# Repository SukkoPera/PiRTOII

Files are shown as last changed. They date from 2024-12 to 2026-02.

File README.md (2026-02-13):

# PiRTO II





PiRTO II if a flash multicart for the Mattel Intellivision based on the Raspberry Pico.

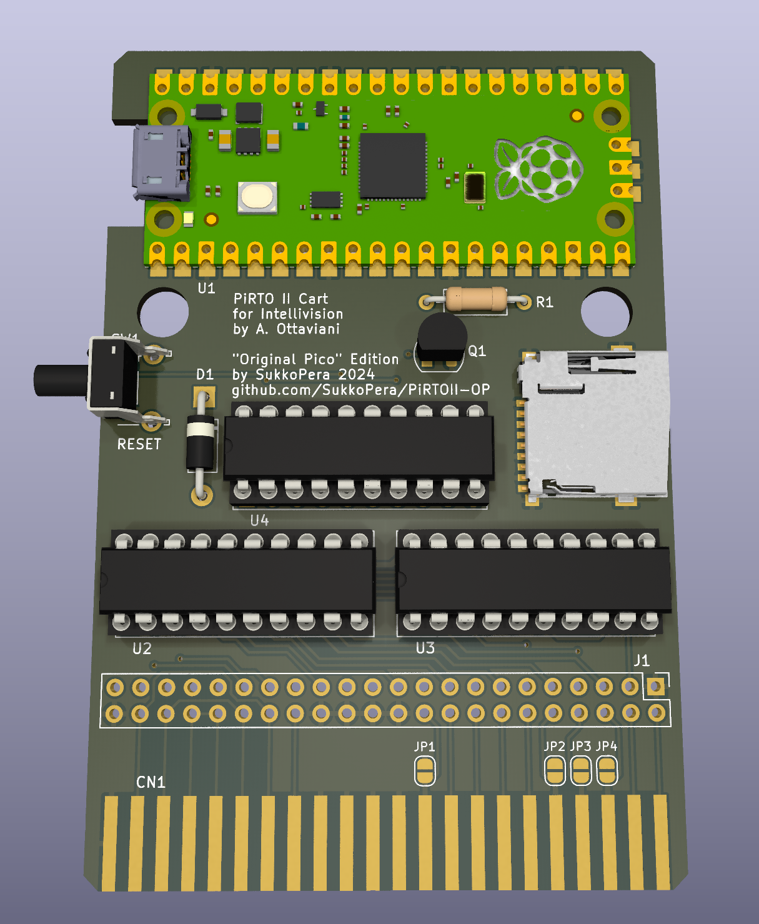
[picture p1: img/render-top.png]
Board


## Summary
This is my variation on [Andrea Ottaviani's PiRTO II](https://github.com/aotta/PiRTOII) flash multicart for the Mattel Intellivision.

My original goal was to adapt it in order to use original Pico boards, of which I had plenty. While studying the project I decided to introduce proper level shifting and a MicroSD card slot (since the original Pico has less flash space than the purple clones used in the original project). All of this eventually made the project very similar to Andrea's [first version of the cart](https://github.com/aotta/PiRTO), of which I was unaware of the time, but it uses through-hole components and one less chip.

## Usage
The Pico must be flashed with some firmware. You have a couple of choices:
- If you want to use Andrea's original firmware, you have to use the version from this page, which was changed to reflect the different pin mapping. Do **NOT** use the firmware from the original project, I will try to incorporate any upstream changes. This firmware has **NO SUPPORT** for the SD card slot.
- storm_walker has updated Andrea's firmware to support the SD card slot. You can get his version from [the sd_support branch](https://github.com/SukkoPera/PiRTOII/tree/sd_support). As far as I'm aware, this version **ONLY** supports the SD card slot. Any ROMs stored in the Pico's flash memory will not be usable.
- Alternatively, you can use [the Minty firmware from Gennaro Tortone](https://github.com/gtortone/Minty), which supports this variant starting from version 1.2. This should support both ROMs from the Pico's flash memory and from the SD card.

For any other needs, please refer to [the original project](https://github.com/aotta/PiRTOII) or to the [AtariAge forum](https://forums.atariage.com/forum/125-intellivision-aquarius/).

## Assembly
This board was designed **for the original Raspberry Pico board**, so either use that or a clone that has the same pinout. It's your responsibility to ascertain that.

U2/3/4 **MUST** be 74LVC245. Do **NOT** get these from China, as they will likely be HC chips with just different (incorrect) markings. Rather get them from Mouser, Digikey, RS, etc.

Other BJTs will probably work for Q1, just make sure they have the same pinout.

JP1/2/3/4 are experimental jumpers and all of them **except** JP4 **MUST** be closed for the moment.

## Releases
If you want to get this board produced, you are recommended to get [the latest release](https://github.com/SukkoPera/PiRTOII/releases) rather than the current git version, as the latter might be under development and is not guaranteed to be working.

Every release is accompanied by its Bill Of Materials (BOM) file and any relevant notes about it, which you are recommended to read carefully.

## License
Despite [an effort to clear things up](https://github.com/aotta/PiRTOII/issues/2), the license status of Andrea's original board is unclear, so I don't really know what to do. I don't want to add or remove any limitations compared to the original project, so please get in touch with him before you use this project in any way.

Still, let me point out that this PiRTOII variation is provided to you ‘as is’ and without any express or implied warranties whatsoever with respect to its functionality, operability or use, including, without limitation, any implied warranties of merchantability, fitness for a particular purpose or infringement. We expressly disclaim any liability whatsoever for any direct, indirect, consequential, incidental or special damages, including, without limitation, lost revenues, lost profits, losses resulting from business interruption or loss of data, regardless of the form of action or legal theory under which the liability may be asserted, even if advised of the possibility or likelihood of such damages.

## Support the Project
If you want to get some boards manufactured, you can get them from PCBWay through this link:

PCB from PCBWay (https://www.pcbway.com/project/shareproject/PiRTOII_Flash_multicart_for_the_Mattel_Intellivision_Original_Pico_Version_95662f2b.html)

You get my gratitude and cheap, professionally-made and good quality PCBs, I get some credit that will help with this and [other projects](https://www.pcbway.com/project/member/?bmbno=72D33927-5EF6-42). You won't even have to worry about the various PCB options, it's all pre-configured for you!

Also, if you still have to register, [you can use this link](https://pcbway.com/g/Nz7XZs) to get some bonus initial credit (and yield me some more).

You can also buy me a coffee if you want, all the money collected this way will actually go to charity:



## Thanks
Of course, I would like to thank Andrea for his original project.

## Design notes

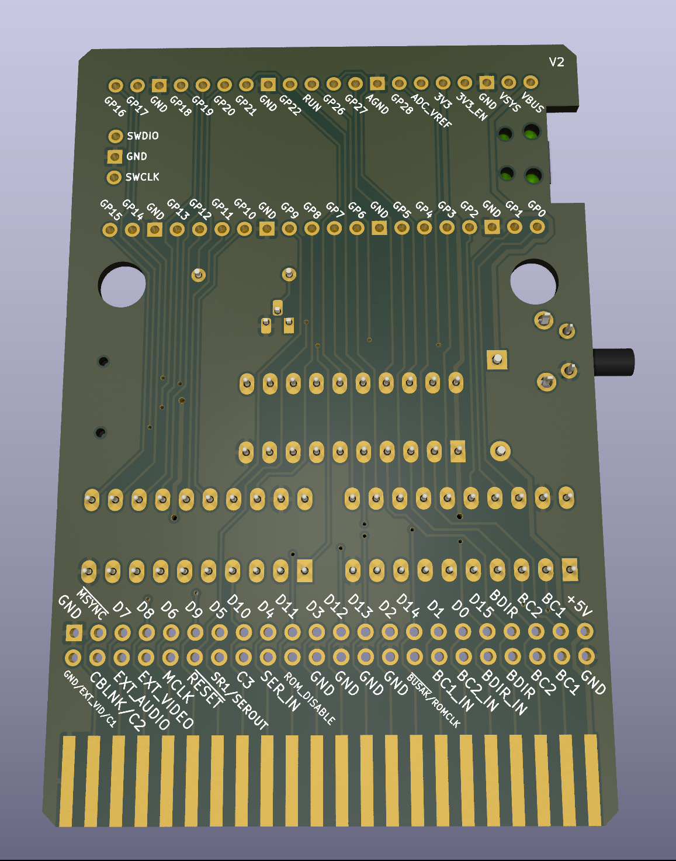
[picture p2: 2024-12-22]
img/render-bottom.png

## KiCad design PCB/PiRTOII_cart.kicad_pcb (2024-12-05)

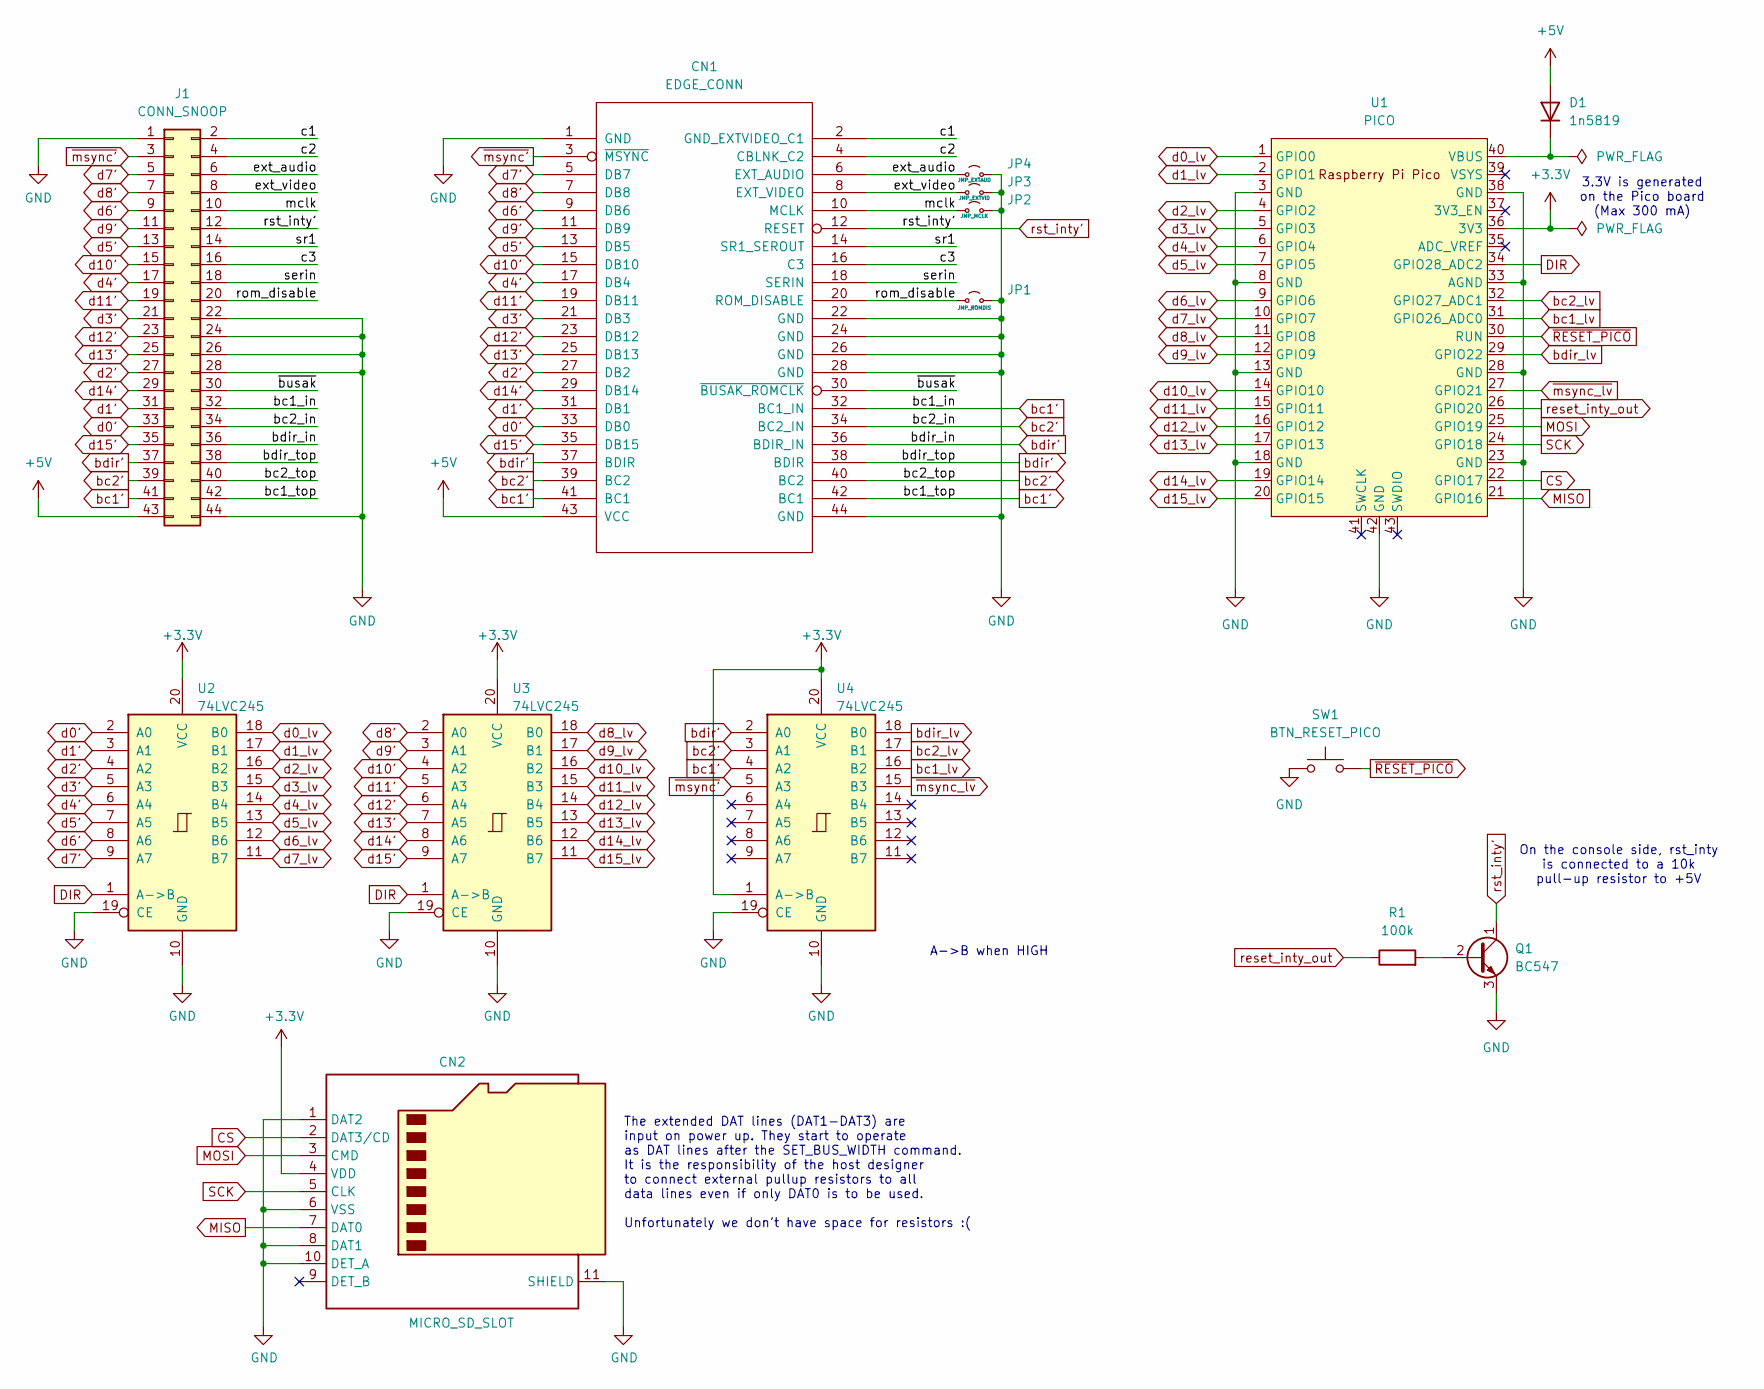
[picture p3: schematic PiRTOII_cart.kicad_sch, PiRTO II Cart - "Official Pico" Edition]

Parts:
CN1: EDGE_CONN; Intellivision_Edge_Connector
CN2: MICRO_SD_SLOT; GCT-MEM2055-00-190-01-A
D1: 1n5819; D_DO-41_SOD81_P10.16mm_Horizontal
J1: CONN_SNOOP; PinHeader_2x22_P2.54mm_Vertical
JP1: JMP_ROMDIS; SolderJumper-2_P1.3mm_Open_RoundedPad1.0x1.5mm
JP2: JMP_MCLK; SolderJumper-2_P1.3mm_Open_RoundedPad1.0x1.5mm
JP3: JMP_EXTVID; SolderJumper-2_P1.3mm_Open_RoundedPad1.0x1.5mm
JP4: JMP_EXTAUD; SolderJumper-2_P1.3mm_Open_RoundedPad1.0x1.5mm
Q1: BC547; TO-92_HandSolder
R1: 100k; R_Axial_DIN0207_L6.3mm_D2.5mm_P10.16mm_Horizontal
SW1: BTN_RESET_PICO; SW_Tactile_SPST_Angled_PTS645Vx83-2LFS
U1: PICO; RPi_Pico_SMD_TH
U2, U3, U4: 74LVC245; DIP-20_W7.62mm_Socket_LongPads

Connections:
+3.3V: CN2.4 (VDD), U1.36 (3V3), U2.20 (VCC), U3.20 (VCC), U4.1 (A->B), U4.20 (VCC)
+5V: CN1.43 (VCC), D1.2 (A), J1.43
/c1: CN1.2 (GND_EXTVIDEO_C1), J1.2
/c2: CN1.4 (CBLNK_C2), J1.4
/c3: CN1.16 (C3), J1.16
/ext_audio: CN1.6 (EXT_AUDIO), J1.6, JP4.1 (A)
/ext_video: CN1.8 (EXT_VIDEO), J1.8, JP3.1 (A)
/mclk: CN1.10 (MCLK), J1.10, JP2.1 (A)
/rom_disable: CN1.20 (ROM_DISABLE), J1.20, JP1.1 (A)
/serin: CN1.18 (SERIN), J1.18
/sr1: CN1.14 (SR1_SEROUT), J1.14
/~busak: CN1.30 (~BUSAK_ROMCLK), J1.30
CS: CN2.2 (DAT3/CD), U1.22 (GPIO17)
DIR: U1.34 (GPIO28_ADC2), U2.1 (A->B), U3.1 (A->B)
GND: CN1.1 (GND), CN1.22 (GND), CN1.24 (GND), CN1.26 (GND), CN1.28 (GND), CN1.44 (GND), CN2.1 (DAT2), CN2.6 (VSS), CN2.8 (DAT1), CN2.10 (DET_A), CN2.11 (SHIELD), J1.1, J1.22, J1.24, J1.26, J1.28, J1.44, JP1.2 (B), JP2.2 (B), JP3.2 (B), JP4.2 (B), Q1.3 (E), SW1.1, U1.3 (GND), U1.8 (GND), U1.13 (GND), U1.18 (GND), U1.23 (GND), U1.28 (GND), U1.33 (AGND), U1.38 (GND), U1.42 (GND), U2.10 (GND), U2.19 (CE), U3.10 (GND), U3.19 (CE), U4.10 (GND), U4.19 (CE)
MISO: CN2.7 (DAT0), U1.21 (GPIO16)
MOSI: CN2.3 (CMD), U1.25 (GPIO19)
unnamed: D1.1 (K), U1.40 (VBUS)
unnamed: Q1.2 (B), R1.2
SCK: CN2.5 (CLK), U1.24 (GPIO18)
bc1': CN1.32 (BC1_IN), CN1.41 (BC1), CN1.42 (BC1), J1.32, J1.41, J1.42, U4.4 (A2)
bc1_lv: U1.31 (GPIO26_ADC0), U4.16 (B2)
bc2': CN1.34 (BC2_IN), CN1.39 (BC2), CN1.40 (BC2), J1.34, J1.39, J1.40, U4.3 (A1)
bc2_lv: U1.32 (GPIO27_ADC1), U4.17 (B1)
bdir': CN1.36 (BDIR_IN), CN1.37 (BDIR), CN1.38 (BDIR), J1.36, J1.37, J1.38, U4.2 (A0)
bdir_lv: U1.29 (GPIO22), U4.18 (B0)
d0': CN1.33 (DB0), J1.33, U2.2 (A0)
d0_lv: U1.1 (GPIO0), U2.18 (B0)
d1': CN1.31 (DB1), J1.31, U2.3 (A1)
d1_lv: U1.2 (GPIO1), U2.17 (B1)
d2': CN1.27 (DB2), J1.27, U2.4 (A2)
d2_lv: U1.4 (GPIO2), U2.16 (B2)
d3': CN1.21 (DB3), J1.21, U2.5 (A3)
d3_lv: U1.5 (GPIO3), U2.15 (B3)
d4': CN1.17 (DB4), J1.17, U2.6 (A4)
d4_lv: U1.6 (GPIO4), U2.14 (B4)
d5': CN1.13 (DB5), J1.13, U2.7 (A5)
d5_lv: U1.7 (GPIO5), U2.13 (B5)
d6': CN1.9 (DB6), J1.9, U2.8 (A6)
d6_lv: U1.9 (GPIO6), U2.12 (B6)
d7': CN1.5 (DB7), J1.5, U2.9 (A7)
d7_lv: U1.10 (GPIO7), U2.11 (B7)
d8': CN1.7 (DB8), J1.7, U3.2 (A0)
d8_lv: U1.11 (GPIO8), U3.18 (B0)
d9': CN1.11 (DB9), J1.11, U3.3 (A1)
d9_lv: U1.12 (GPIO9), U3.17 (B1)
d10': CN1.15 (DB10), J1.15, U3.4 (A2)
d10_lv: U1.14 (GPIO10), U3.16 (B2)
d11': CN1.19 (DB11), J1.19, U3.5 (A3)
d11_lv: U1.15 (GPIO11), U3.15 (B3)
d12': CN1.23 (DB12), J1.23, U3.6 (A4)
d12_lv: U1.16 (GPIO12), U3.14 (B4)
d13': CN1.25 (DB13), J1.25, U3.7 (A5)
d13_lv: U1.17 (GPIO13), U3.13 (B5)
d14': CN1.29 (DB14), J1.29, U3.8 (A6)
d14_lv: U1.19 (GPIO14), U3.12 (B6)
d15': CN1.35 (DB15), J1.35, U3.9 (A7)
d15_lv: U1.20 (GPIO15), U3.11 (B7)
reset_inty_out: R1.1, U1.26 (GPIO20)
rst_inty': CN1.12 (RESET), J1.12, Q1.1 (C)
~RESET_PICO: SW1.2, U1.30 (RUN)
~msync': CN1.3 (~MSYNC), J1.3, U4.5 (A3)
~msync_lv: U1.27 (GPIO21), U4.15 (B3)

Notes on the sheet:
A->B when HIGH
3.3V is generated on the Pico board (Max 300 mA)
On the console side, rst_inty is connected to a 10k pull-up resistor to +5V
The extended DAT lines (DAT1-DAT3) are input on power up. They start to operate as DAT lines after the SET_BUS_WIDTH command. It is the responsibility of the host designer to connect external pullup resistors to all data lines even if only DAT0 is to be used. Unfortunately we don't have space for r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

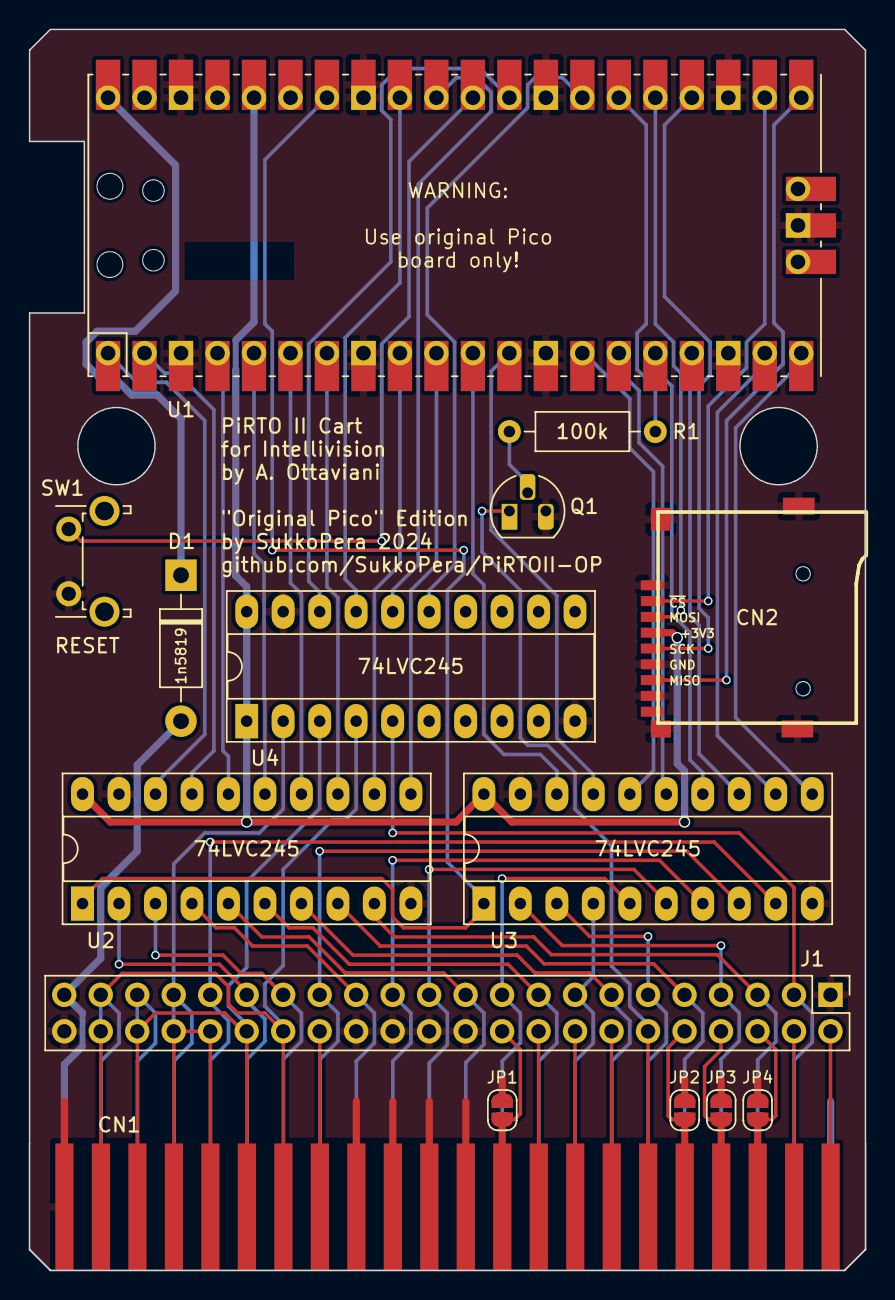
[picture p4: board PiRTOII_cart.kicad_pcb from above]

Board: 2 copper layers, 58.2 x 86.4 mm, 15 parts (0 on the bottom side), 63 nets.

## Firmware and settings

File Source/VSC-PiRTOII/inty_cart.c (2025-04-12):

/*
//                       PiRTO II Flash MultiCART by Andrea Ottaviani 2024
//
//  Intellivision flash multicart based on Raspberry Pico board -
//
//  More info on https://github.com/aotta/ 
//
//   parts of code are directly from the A8PicoCart project by Robin Edwards 2023
//  
//   Needs to be a release NOT debug build for the cartridge emulation to work
// 
//   Edit myboard.h depending on the type of flash memory on the pico clone//
//
//   v. 1.0 2024-05-04 : Initial version for Pi Pico 
//
*/

//#define intydebug // for debug print on intyscreen

#include <stdio.h>
#include <stdlib.h>
#include <string.h>
#include "pico/multicore.h"
#include "hardware/gpio.h"
#include "pico/platform.h"
#include "pico/stdlib.h"
#include "hardware/vreg.h"
#include "pico/divider.h"
#include "hardware/flash.h"
#include "hardware/sync.h"
#include "hardware/clocks.h"

#include "rom.h"

#include "tusb.h"
#include "ff.h"
#include "fatfs_disk.h"

#include "inty_cart.h"


// Pico pin usage definitions

#define B0_PIN    0
#define B1_PIN    1
#define B2_PIN    2
#define B3_PIN    3
#define B4_PIN    4
#define B5_PIN    5
#define B6_PIN    6
#define B7_PIN    7
#define F0_PIN    8
#define F1_PIN    9
#define F2_PIN    10
#define F3_PIN    11
#define F4_PIN    12
#define F5_PIN    13
#define F6_PIN    14
#define F7_PIN    15
#define BDIR_PIN  22
#define BC2_PIN   27
#define BC1_PIN   26
#define MSYNC_PIN 21
#define RST_PIN   20
#define LED_PIN   25
#define DIR_PIN   28	//  TO PIN 1 LVC245, HIGH= A->B (INPUT 5V TO 3.3V, inty -> pico) LOW= B->A (OUTPUT 3.3V TO 5V, pico -> inty)

// Pico pin usage masks
#define B0_PIN_MASK     0x00000001L // gpio 0
#define B1_PIN_MASK     0x00000002L
#define B2_PIN_MASK     0x00000004L
#define B3_PIN_MASK     0x00000008L
#define B4_PIN_MASK     0x00000010L
#define B5_PIN_MASK     0x00000020L
#define B6_PIN_MASK     0x00000040L
#define B7_PIN_MASK     0x00000080L

#define F0_PIN_MASK     0x00000100L
#define F1_PIN_MASK     0x00000200L
#define F2_PIN_MASK     0x00000400L
#define F3_PIN_MASK     0x00000800L
#define F4_PIN_MASK     0x00001000L
#define F5_PIN_MASK     0x00002000L
#define F6_PIN_MASK     0x00004000L
#define F7_PIN_MASK     0x00008000L  // gpio 15

#define BDIR_PIN_MASK   0x00400000L // gpio 22
#define BC2_PIN_MASK    0x08000000L // gpio 27
#define BC1_PIN_MASK    0x04000000L // gpio 26
#define MSYNC_PIN_MASK  0x00200000L // gpio 21
#define RST_PIN_MASK    0x00100000L // gpio 20
#define LED_PIN_MASK    0x02000000L // gpio 25
#define DIR_PIN_MASK	0x10000000L	// gpio 28


// Aggregate Pico pin usage masks
#define BC1e2_PIN_MASK  (BC1_PIN_MASK | BC2_PIN_MASK)
#define BX_PIN_MASK     (B0_PIN_MASK | B1_PIN_MASK | B2_PIN_MASK | B3_PIN_MASK | B4_PIN_MASK | B5_PIN_MASK | B6_PIN_MASK | B7_PIN_MASK)
#define FX_PIN_MASK     (F0_PIN_MASK | F1_PIN_MASK | F2_PIN_MASK | F3_PIN_MASK | F4_PIN_MASK | F5_PIN_MASK | F6_PIN_MASK | F7_PIN_MASK)
#define DATA_PIN_MASK   (BX_PIN_MASK | FX_PIN_MASK)
                         
#define BUS_STATE_MASK  (BDIR_PIN_MASK | BC1_PIN_MASK | BC2_PIN_MASK)
//~ #define ALL_GPIO_MASK  	(DATA_PIN_MASK | BUS_STATE_MASK | MSYNC_PIN_MASK | RST_PIN_MASK | LED_PIN_MASK)
#define ALWAYS_IN_MASK  (BUS_STATE_MASK)
#define ALWAYS_OUT_MASK (LED_PIN_MASK | DIR_PIN_MASK)

#define SET_DATA_MODE_OUT   do {gpio_clr_mask(DIR_PIN_MASK); gpio_set_dir_out_masked(DATA_PIN_MASK);} while (0)
#define SET_DATA_MODE_IN    do {gpio_set_dir_in_masked(DATA_PIN_MASK); gpio_set_mask(DIR_PIN_MASK);} while (0)

#define resetLow()  gpio_set_dir(RST_PIN,true); gpio_put(RST_PIN,true); //  Pirto to INTV BUS ; RST Output set to 0
#define resetHigh() gpio_set_dir(RST_PIN,true); gpio_put(RST_PIN,false); // RST is INPUT; B->A, INTV BUS to TEENSY

// Inty bus values (BC1+BC2+BDIR) GPIO 18-17-16

#define BUS_NACT  0b000  //0
#define BUS_BAR   0b001  //1
#define BUS_IAB   0b010  //2
#define BUS_DWS   0b011  //3
#define BUS_ADAR  0b100  //4
#define BUS_DW    0b101  //5
#define BUS_DTB   0b110  //6
#define BUS_INTAK 0b111  //7


unsigned char busLookup[8];

char RBLo,RBHi;
#define BINLENGTH  1024*64 //65536L
#define RAMSIZE  0x2000		// 8 kB
uint16_t ROM[BINLENGTH];

uint16_t RAM[RAMSIZE];
#define maxHacks 32
uint16_t HACK[maxHacks];
uint16_t HACK_CODE[maxHacks];

char curPath[256] = "";
char path[256];
unsigned char files[256*64] = {0};
unsigned char nomefiles[32*25] = {0};
int fileda=0,filea=0;
volatile char cmd=0;
char errorBuf[40];
bool cmd_executing=false;

unsigned int parallelBus2;
  
unsigned int romLen;
unsigned int ramfrom = 0;
unsigned int ramto =   0;
unsigned int mapfrom[80];
unsigned int mapto[80];
unsigned int maprom[80];
int mapdelta[80];
unsigned int mapsize[80];
unsigned int addrto[80];
unsigned int RAMused = 0;
unsigned int tipo[80];  // 0-rom / 1-page / 2-ram
unsigned int page[80];  // page number

char substr[100];

int slot;
int hacks;

int base=0x17f;

uint32_t selectedfile_size;    // BIN file size
char longfilename[60];         // long file name (trunked) 
char mapfilename[60];          // map cfg file name
char testfilename[60];         // for check if directory
char rewindfilename[60];       // for rewind browsing
char rewindprev[60];       // for rewind browsing
int lenfilename; 
char tiposcelta[9];
bool pressed=false;


////////////////////////////////////////////////////////////////////////////////////
//                     RESET
////////////////////////////////////////////////////////////////////////////////////
void resetCart() {
  gpio_init(MSYNC_PIN);
  gpio_set_dir(MSYNC_PIN,false);
  gpio_set_pulls(MSYNC_PIN,false,true);
  gpio_put(LED_PIN,false);
  resetHigh();
   sleep_ms(30);  // was 20 for Model II; 30 works for both
   resetLow();
  //sleep_ms(3);  // was 2 for Model II; 3 works for both
 
  //while ((gpio_get(MSYNC_PIN)==1)) ;
    
  sleep_ms(1);  // was 1 for Model II; 
 resetHigh();
 gpio_put(LED_PIN,true);
   
}


/*
 Theory of Operation
 -------------------
 Inty sends command to mcu on cart by writing to 50000 (CMD), 50001 (parameter) and menu (50002-50641) 
 Inty must be running from RAM when it sends a command, since the mcu on the cart will
 go away at that point. Inty polls 50001 until it reads $1.
*/

void __not_in_flash_func(core1_main()) {

  unsigned int lastBusState, busState1;
  unsigned int busSt1, busSt2;
  unsigned int parallelBus;
  unsigned int dataOut, dataInd;
  unsigned int dataWrite=0;
  unsigned char busBit;
  bool deviceAddress = false; 
  unsigned int curPage=0;
  unsigned int checpage=0;
  int exitBUS;

  multicore_lockout_victim_init();	

  sleep_ms(480);

  busState1 = BUS_NACT;
  lastBusState = BUS_NACT;
  
  dataOut=0;

    gpio_set_dir_in_masked(ALWAYS_IN_MASK);
    gpio_set_dir_out_masked(ALWAYS_OUT_MASK);
 
    // Initial conditions
    SET_DATA_MODE_IN;
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

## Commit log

2024-12-05 Use original Pico board
    [PiRTOII_cart.kicad_pcb, PiRTOII_cart.kicad_sch]
2024-12-05 Almost there
    [PiRTOII_cart.kicad_pcb, PiRTOII_cart.kicad_sch]
2024-12-05 Add MicroSD slot
    [PiRTOII_cart.kicad_pcb, PiRTOII_cart.kicad_sch]
2024-12-05 Use better BJT footprint
    [PiRTOII_cart.kicad_pcb, PiRTOII_cart.kicad_sch]
2024-12-05 Add SD slot signal labels (?)
    [PiRTOII_cart.kicad_pcb, PiRTOII_cart.kicad_sch]
2024-12-05 Adapt code to original Pico board
2024-12-22 Remove files that can be found upstream
    [PiRTOII_Cart-Bot (Meshed).stl, PiRTOII_Cart-Logo (Meshed).stl, PiRTOII_Cart-Top (Meshed).stl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]
2025-04-12 Fix max number of dir entries
    (cherry picked from upstream commit bd78ca32517b8900df6ca5afb25b20ff275c1429)
    [inty_cart.c]
